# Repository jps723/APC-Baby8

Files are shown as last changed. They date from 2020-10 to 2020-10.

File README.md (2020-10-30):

# APCBaby8 Build Notes 2/16/20

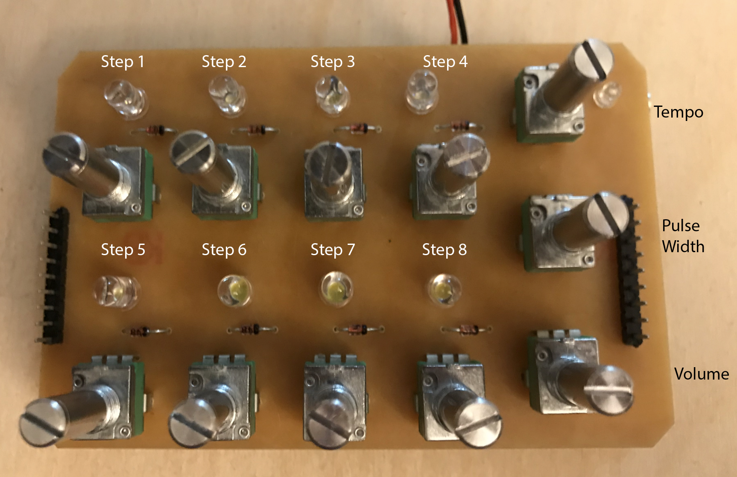
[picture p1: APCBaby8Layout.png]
A handheld Atari Punk Console and Baby 8 Sequencer sits on a table


This project is in partnership with [Bantam Tools](https://www.bantamtools.com)

**Design Notes:**

This design is based on the Atari Punk Console and the Baby8 Step Sequencer.  It utilizes three 555 timers, and a 4017 decade counter, to emit a square wave in a repeating series of frequencies.  It’s a stackable design broken into UI and Utility boards.

The design operates off of 9v, with ‘+/-‘ symbols etched into the top layer of the bottom board, indicating polarity. There are additional ‘–‘ etchings indicating the required ‘notch’ orientation for all of the ICs.  The arrows indicate the directions that the boards should be facing when stacked.

The UI board contains 11 variable resistors in total; 8 for defining the pitch to be played in the sequencer, and three others for controlling the rate at which the sequence advances, the pulse width of the oscillation, and the master volume.

Each of the 8 pitch variable resistors is connected to an output pin of a 4017 decade counter (located on the utility board), which counts through the 8 step sequence.  As each step is passed, the emitted voltage as determined by the position of the pot is applied to oscillator A of the APC, affecting its frequency.  Each step has an associated LED located above it for indicating which step is being played. The 1N4148 diode is for preventing noise from unintended steps.

The Utility board contains the decade counter, a 555 timer that serves as the master clock, and two more 555 timers serving as oscillators A and B for the APC.  Oscillator A is in astable mode, and oscillator B is in monostable mode, with its trigger coming from the output of oscillator A.  Oscillator B has a pot connected to it for varying the pulse width of the oscillation. The 4017 decade counter emits 10 steps, however step 9 triggers the reset pin, limiting the sequence to 8.  The output voltage from the stepped variable resistors are applied to the discharge pin on Oscillator B, dictating the charge rate of the attached capacitor, and ultimately the oscillation frequency.

## **Build Process:**

**Bottom Board:**
**Top Layer:**
Bits: 1/32” / 1/64”
Mill Time: ~4 ½mins

**Bottom Layer:**
Bits: 1/32” / 1/64”
Mill Time: ~14 ½mins

**Top Board:
Bottom Layer:**
Bits: 1/32” / 1/64”
Mill Time: ~17 ½mins

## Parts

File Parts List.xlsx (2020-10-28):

Part | Quantity | Notes
UI Board
100k Potentiometers | 10 | Footprint: https://www.mouser.com/ProductDetail/858-P0915NEC20BR100K
1M Potentiometer | 1 | Footprint: https://www.mouser.com/ProductDetail/858-P0915NEC20BR100K
1N4148 Diodes | 8 | Through-hole
5mm LEDs | 9 | Through-hole
1k Resistors | 12 | 0805 SMD 10 on UI, 2 on Utility
Extra Long (19mm) .1" Male Headers | 2 | 1x9 Ref: https://www.amazon.com/SUNKEE-Break-Away-Header-Straight/dp/B00C0Q5XZ4?s=hi
Utility Board
Dip Sockets
 | 3 | 2x4
 | 1 | 2x8
ICs
555 Timer | 3
4017 Decade Counter | 1
Ceramic Capacitors | 2 | 0805 SMD .1uF
Electrolyric Capacitors | 2 | Electrolytic SMD 47uF
Screw Terminal | 1 | 2x1
3.5mm Horizontal Stereo Jack | 1 | Footprint: https://www.amazon.com/gp/product/B008SNZUYC/ref=ppx_yo_dt_b_asin_title_o04_s00?ie=UTF8&psc=1
.1" Female Headers | 2 | 1x9 Ref: https://www.amazon.com/gp/product/B076GZXW3Z/ref=ppx_yo_dt_b_search_asin_title?ie=UTF8&psc=1

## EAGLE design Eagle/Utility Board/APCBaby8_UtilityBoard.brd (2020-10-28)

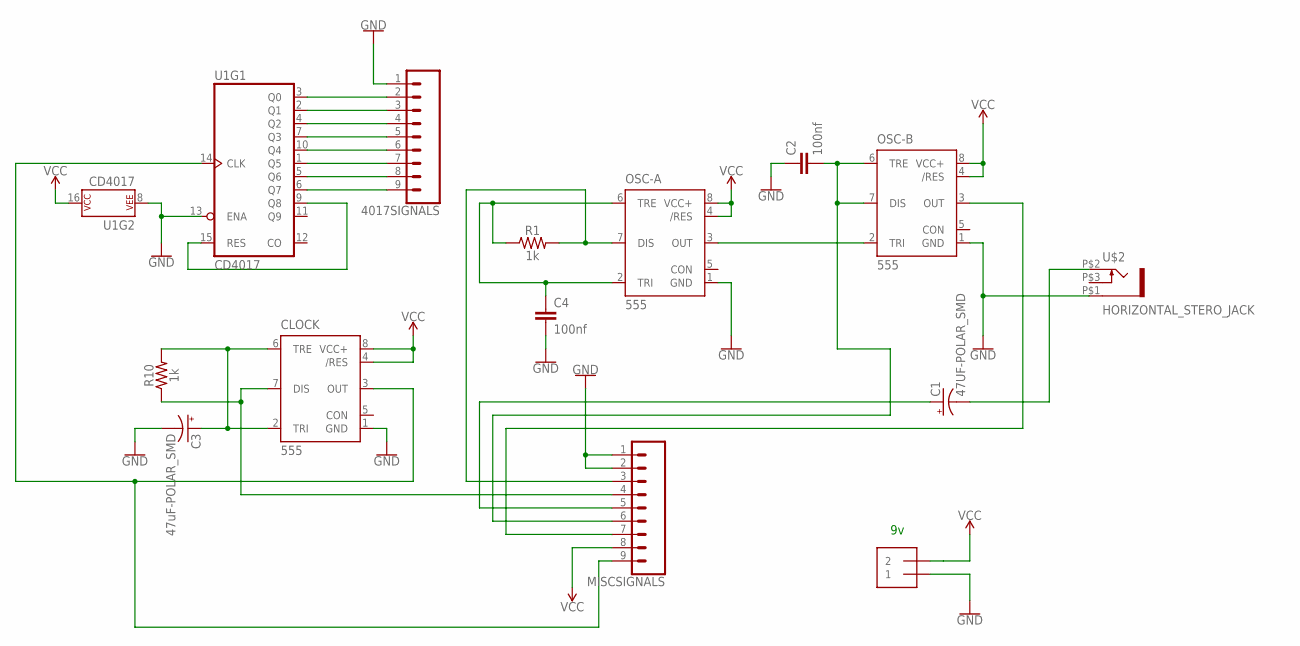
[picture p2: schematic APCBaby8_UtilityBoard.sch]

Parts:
9V: 9v; 1X2-3.5MM
4017SIGNALS: CONN_09LONGPADS; 1X09_LONGPADS
C1: 47UF-POLAR_SMD; PANASONIC_D
C2, C4: 100nf; 0805
C3: 47uF-POLAR_SMD; PANASONIC_D
CLOCK: 555; DIP08-KIT
MISCSIGNALS: CONN_09LONGPADS; 1X09_LONGPADS
OSC-A: 555; DIP08-KIT
OSC-B: 555; DIP08-KIT
R1, R10: 1k; 0805
U1: CD4017; DIP16
U$2: HORIZONTAL_STERO_JACK; HORIZONTAL_STEREO_JACK

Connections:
CLOCK: CLOCK.3 (OUT), MISCSIGNALS.9, U1.14 (CLK)
GND: 9V.1, 4017SIGNALS.1, C2.1, C3.-, C4.2, CLOCK.1 (GND), MISCSIGNALS.1, MISCSIGNALS.2, OSC-A.1 (GND), OSC-B.1 (GND), U1.8 (P$V-), U1.13 (ENA), U$2.P$1 (1)
unnamed: 4017SIGNALS.2, U1.3 (Q0)
unnamed: 4017SIGNALS.3, U1.2 (Q1)
unnamed: 4017SIGNALS.4, U1.4 (Q2)
unnamed: 4017SIGNALS.5, U1.7 (Q3)
unnamed: 4017SIGNALS.6, U1.10 (Q4)
unnamed: 4017SIGNALS.7, U1.1 (Q5)
unnamed: 4017SIGNALS.8, U1.5 (Q6)
unnamed: 4017SIGNALS.9, U1.6 (Q7)
unnamed: C1.-, U$2.P$2 (2)
unnamed: C3.+, CLOCK.2 (TRI), CLOCK.6 (TRE), R10.2
unnamed: C4.1, OSC-A.2 (TRI), OSC-A.6 (TRE), R1.1
unnamed: OSC-A.3 (OUT), OSC-B.2 (TRI)
OUT: MISCSIGNALS.7, OSC-B.3 (OUT)
PUSESIG: C2.2, MISCSIGNALS.6, OSC-B.6 (TRE), OSC-B.7 (DIS)
RESET: U1.9 (Q8), U1.15 (RES)
STEPSIG: MISCSIGNALS.3, OSC-A.7 (DIS), R1.2
TEMPOSIG: CLOCK.7 (DIS), MISCSIGNALS.4, R10.1
VCC: 9V.2, CLOCK.4 (/RES), CLOCK.8 (VCC+), MISCSIGNALS.8, OSC-A.4 (/RES), OSC-A.8 (VCC+), OSC-B.4 (/RES), OSC-B.8 (VCC+), U1.16 (P$V+)
VOLSIG: C1.+, MISCSIGNALS.5

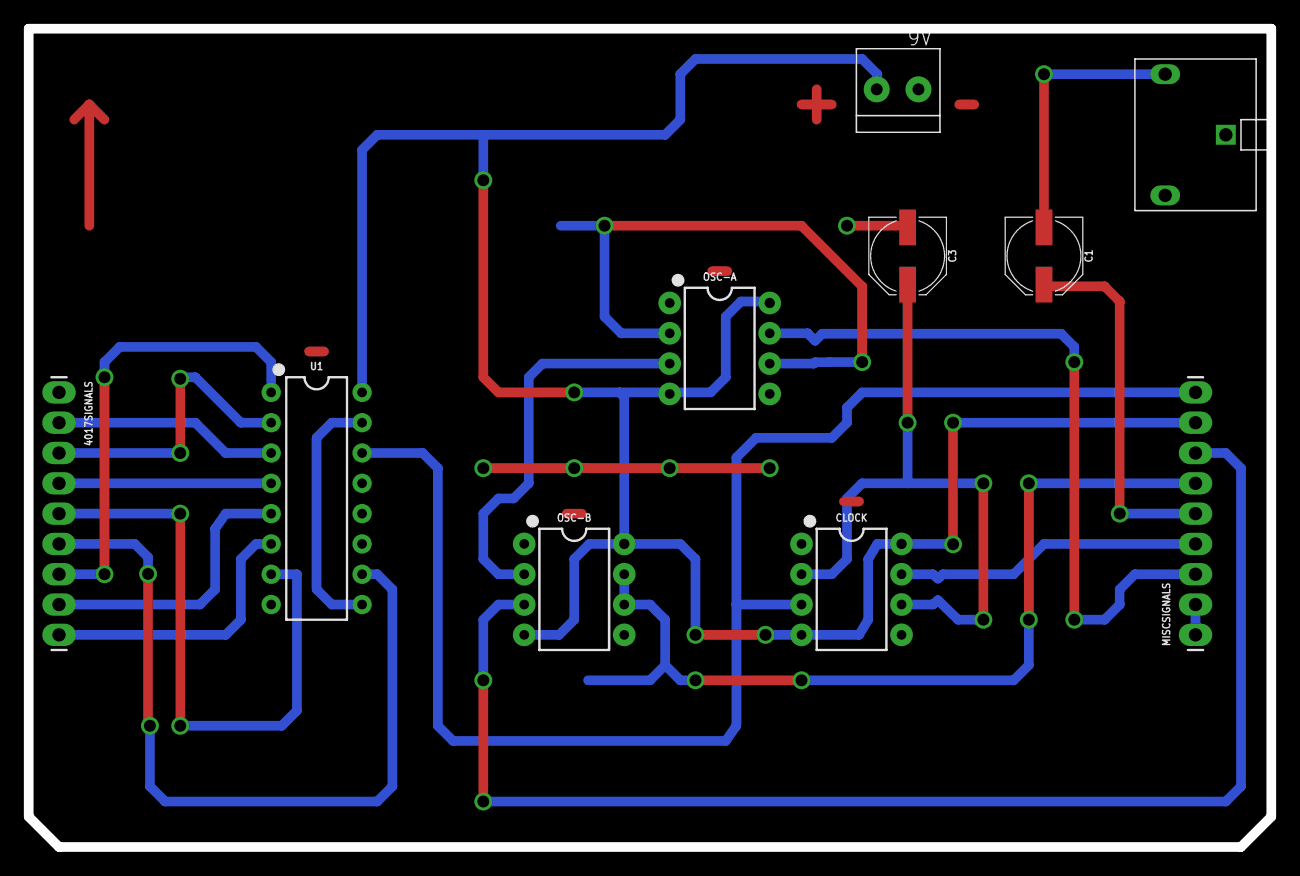
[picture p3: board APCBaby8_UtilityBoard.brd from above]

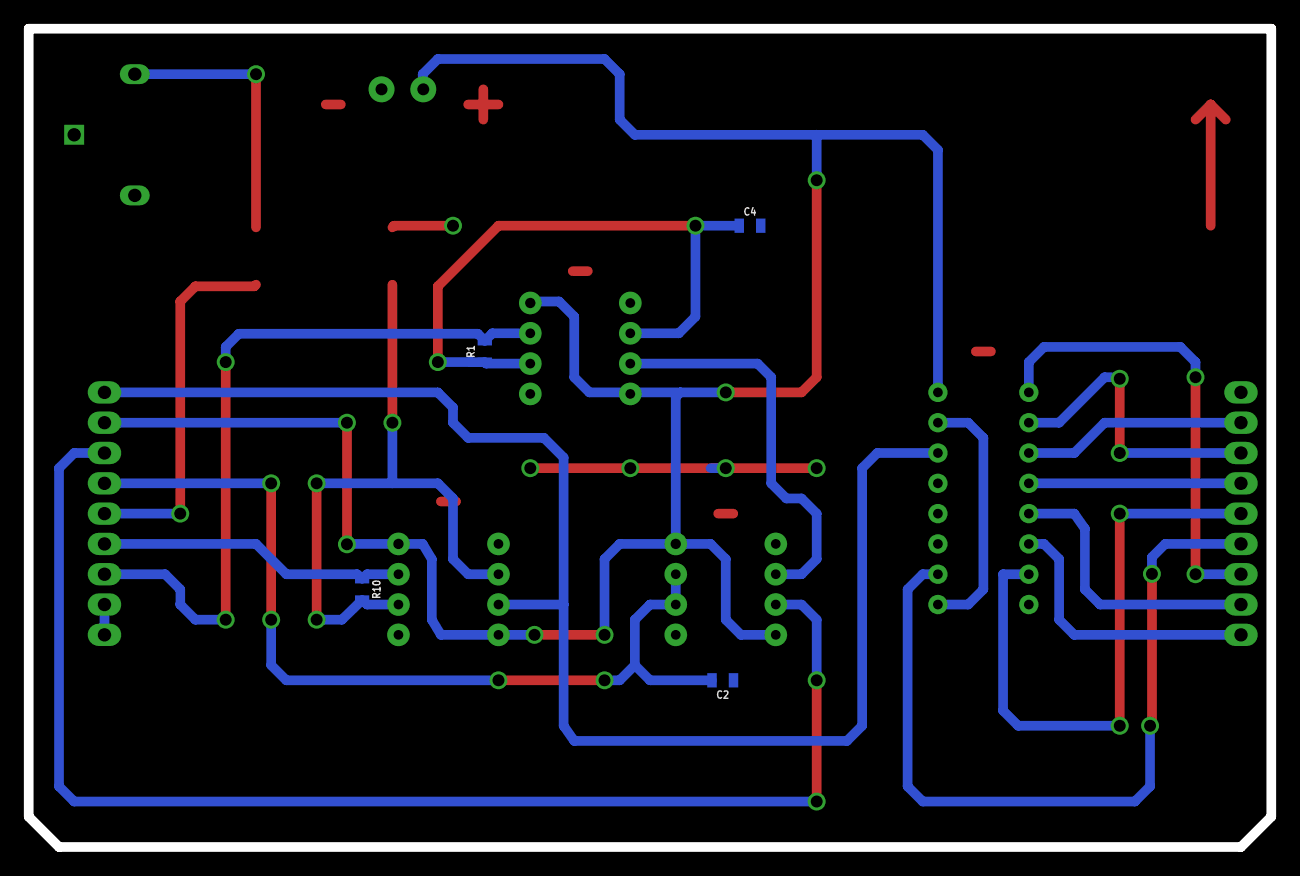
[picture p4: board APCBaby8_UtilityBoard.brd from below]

Board: 2 copper layers, 104.1 x 68.6 mm, 14 parts (4 on the bottom side), 21 nets.

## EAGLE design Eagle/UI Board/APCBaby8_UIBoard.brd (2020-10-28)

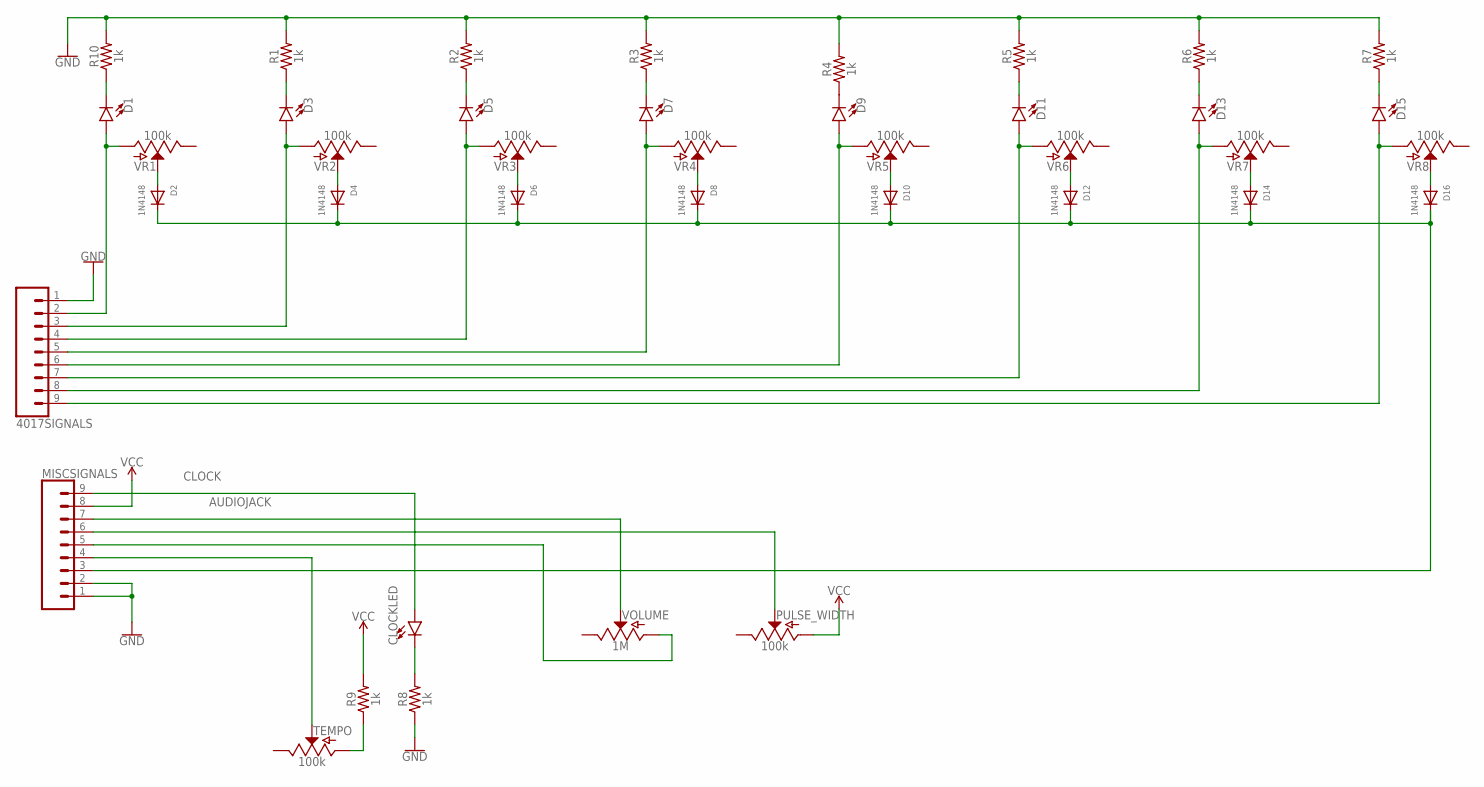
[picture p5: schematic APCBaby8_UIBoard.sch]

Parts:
4017SIGNALS: CONN_09LONGPADS; 1X09_LONGPADS
CLOCKLED: LED-3MM-NO_SILK; LED_3MM-NS
D1, D3, D5, D7, D9, D11, D13, D15: LED-3MM-NO_SILK; LED_3MM-NS
D2, D4, D6, D8, D10, D12, D14, D16: 1N4148; DO-1N4148
MISCSIGNALS: CONN_09LONGPADS; 1X09_LONGPADS
PULSE_WIDTH: 100k; POT-PTH-ALPS
R1, R2, R3, R4, R5, R6, R7, R8, R9, R10: 1k; 0805
TEMPO: 100k; POT-PTH-ALPS
VOLUME: 1M; POT-PTH-ALPS
VR1, VR2, VR3, VR4, VR5, VR6, VR7, VR8: 100k; POT-PTH-ALPS

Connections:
AUDIOJACK: MISCSIGNALS.7, VOLUME.P$2 (S)
CLOCK: CLOCKLED.A, MISCSIGNALS.9
GND: 4017SIGNALS.1, MISCSIGNALS.1, MISCSIGNALS.2, R1.2, R2.2, R3.2, R4.2, R5.2, R6.2, R7.2, R8.1, R10.2
unnamed: D9.K (C), R4.1
unnamed: D2.A, VR1.P$2 (S)
unnamed: D1.K (C), R10.1
unnamed: D4.A, VR2.P$2 (S)
unnamed: D3.K (C), R1.1
unnamed: R9.1, TEMPO.P$3 (A)
unnamed: D6.A, VR3.P$2 (S)
unnamed: D5.K (C), R2.1
unnamed: D8.A, VR4.P$2 (S)
unnamed: D7.K (C), R3.1
unnamed: D10.A, VR5.P$2 (S)
unnamed: D12.A, VR6.P$2 (S)
unnamed: D11.K (C), R5.1
unnamed: D14.A, VR7.P$2 (S)
unnamed: D13.K (C), R6.1
unnamed: D16.A, VR8.P$2 (S)
unnamed: D15.K (C), R7.1
unnamed: CLOCKLED.K (C), R8.2
PULSESIG: MISCSIGNALS.6, PULSE_WIDTH.P$2 (S)
STEP1: 4017SIGNALS.2, D1.A, VR1.P$3 (A)
STEP2: 4017SIGNALS.3, D3.A, VR2.P$3 (A)
STEP3: 4017SIGNALS.4, D5.A, VR3.P$3 (A)
STEP4: 4017SIGNALS.5, D7.A, VR4.P$3 (A)
STEP5: 4017SIGNALS.6, D9.A, VR5.P$3 (A)
STEP6: 4017SIGNALS.7, D11.A, VR6.P$3 (A)
STEP7: 4017SIGNALS.8, D13.A, VR7.P$3 (A)
STEP8: 4017SIGNALS.9, D15.A, VR8.P$3 (A)
STEPDIODES: D2.C, D4.C, D6.C, D8.C, D10.C, D12.C, D14.C, D16.C, MISCSIGNALS.3
TEMPOSIG: MISCSIGNALS.4, TEMPO.P$2 (S)
VCC: MISCSIGNALS.8, PULSE_WIDTH.P$3 (A), R9.2
VOLSIG: MISCSIGNALS.5, VOLUME.P$3 (A)

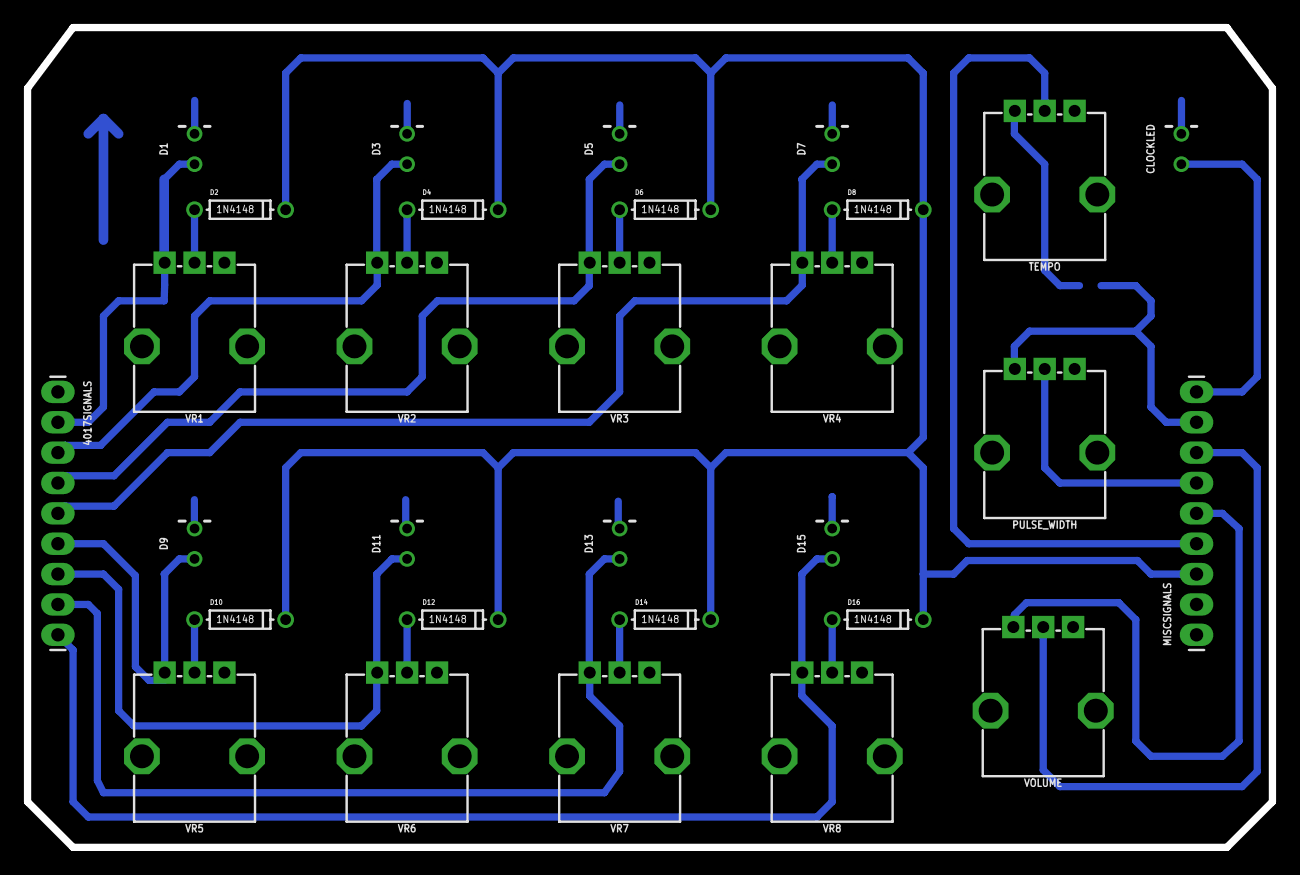
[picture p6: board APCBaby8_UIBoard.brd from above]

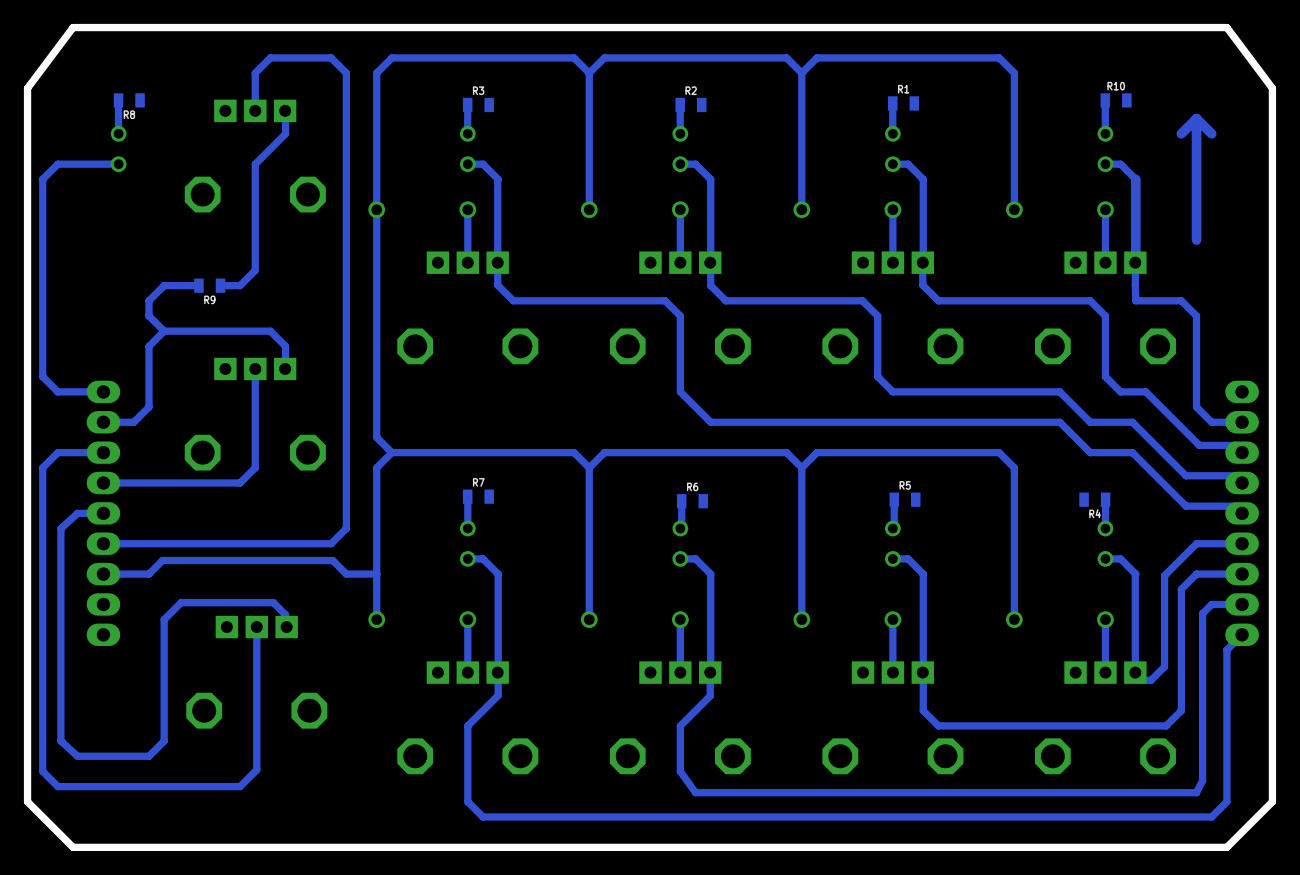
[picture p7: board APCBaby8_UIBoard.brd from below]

Board: 2 copper layers, 104.1 x 68.6 mm, 40 parts (10 on the bottom side), 34 nets.

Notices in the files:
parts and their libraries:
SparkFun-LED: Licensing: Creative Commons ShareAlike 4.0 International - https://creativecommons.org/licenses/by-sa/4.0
